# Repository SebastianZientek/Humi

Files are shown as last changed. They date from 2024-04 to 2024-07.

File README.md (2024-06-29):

# Klarta Humea WiFi Module Replacement

## Overview

This project offers a replacement WiFi module for the Klarta Humea humidifier, enabling users to control the device via a web interface. The project is written in C++ and utilizes the ESP8266 platform.

## Features
- Web-based control interface for managing the humidifier remotely.
- Custom PCB.
- Update firmware by OTA (On The Air)
- Control device over MQTT (allows integration with Home Assistant).

## PCB
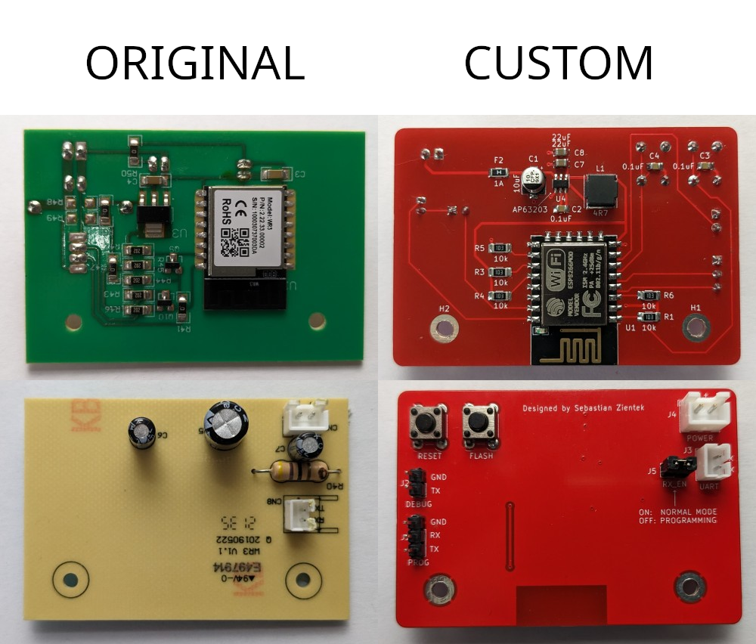
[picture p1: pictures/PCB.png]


## Web configuration portal
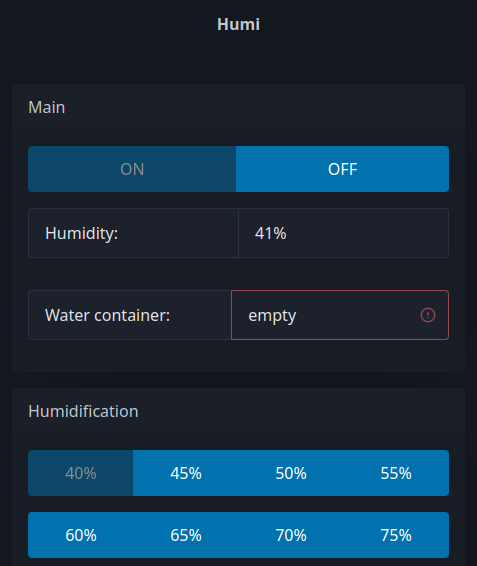
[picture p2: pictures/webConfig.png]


## Disclaimer

**Use at Your Own Risk**: This project is created for fun. While it works for me, I'm not an electronic engineer so keep in mind that PCB design can have mistakes.

## Getting Started

### Prerequisites

- [PlatformIO](https://platformio.org/) installed on your development environment (platformio-core or as plugin to your IDE).
- USB to TTL adapter for flashing the firmware.
- Prepared PCB (gerber files under pcb directory, values of components included on silkscreen)

### Firmware preparation
1. Clone this repository to your local machine:

   ```bash
   git clone https://github.com/SebastianZientek/Humi.git
   ```

2. Navigate to the project directory:

   ```bash
   cd Humi
   ```

### Flashing firmware

1. Connect the USB to TTL adapter to the `PROG` header on the custom PCB.

2. Connect the USB to TTL adapter to your computer.

3. Power on the Klarta Humea humidifier with the replacement WiFi module installed.

4. Disconnect jumper RX_EN.

5. Build and upload firmware to the board:

   ```bash
   pio run -t upload
   ```
6. Connect jumper back.

### First setup

1. Power on the Klarta Humea humidifier with the replacement WiFi module installed.
2. Connect to network hosted by humidifier (ssid: HumiConnectToWiFi).
3. Open a web browser and navigate to the `http://192.168.4.1`.
4. Set up wifi network that humidifier should use.

## Custom PCB

Custom PCB designs are provided under `PCB` directory. These files can be used to manufacture the replacement WiFi module PCB.

## License

This project is licensed under the [MIT License](LICENSE).

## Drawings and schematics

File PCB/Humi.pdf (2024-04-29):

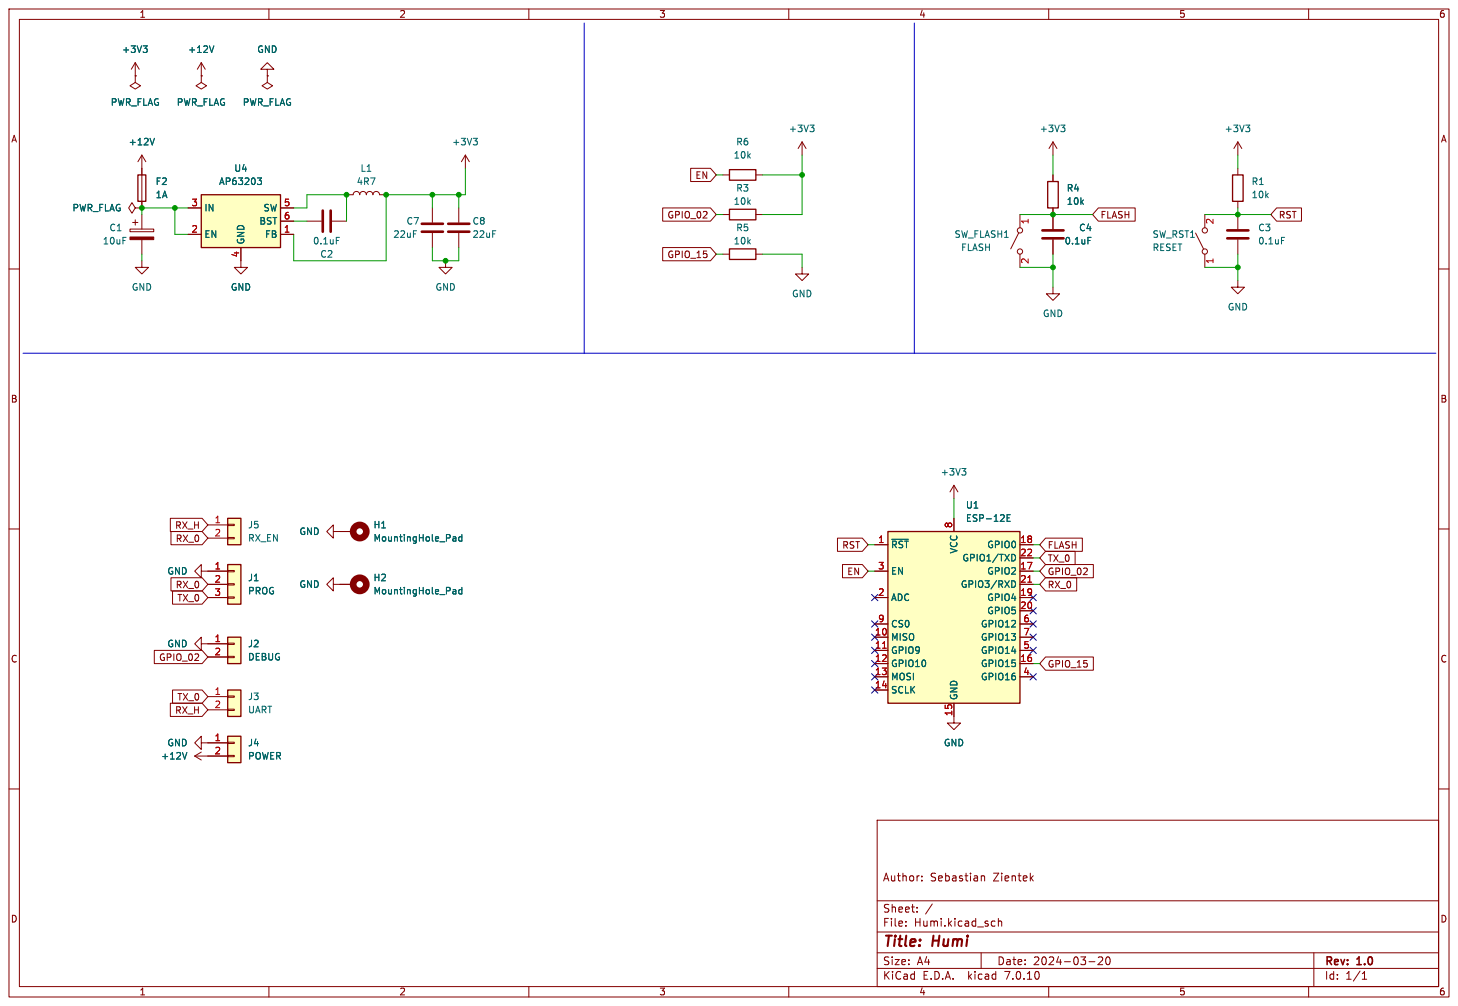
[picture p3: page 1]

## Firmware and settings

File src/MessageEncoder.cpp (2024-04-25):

#include "MessageEncoder.hpp"

#include <algorithm>
#include <iterator>
#include <map>
#include <numeric>
#include <optional>

namespace
{
constexpr auto preambleSize = 2;
constexpr auto headerSize = 6;
constexpr auto valueSize = 1;
constexpr auto checkSumSize = 1;
constexpr auto payloadSizeByteIndex = 5;

const std::map<std::string, std::vector<uint8_t>> encodingMap{
    {"power", {0, 6, 0, 5, 10, 1, 0, 1}},
    {"humidification_power", {0, 6, 0, 5, 106, 4, 0, 1}},
    {"humidification_level", {0, 6, 0, 5, 105, 4, 0, 1}},
    {"night_mode", {0, 6, 0, 5, 103, 1, 0, 1}},
    {"auto_mode", {0, 6, 0, 5, 104, 1, 0, 1}},
    {"light", {0, 6, 0, 5, 102, 4, 0, 1}},
    {"timer", {0, 6, 0, 5, 108, 4, 0, 1}},
    {"wifi_indicator", {0, 3, 0, 1}}};

const std::map<std::vector<uint8_t>, std::string> decodingMap{
    {{0, 0, 0}, "i_am_alive"},
    {{3, 4, 0}, "wifi_pair"},
    {{3, 7, 0, 5, 10, 1, 0, 1}, "power"},
    {{3, 7, 0, 5, 106, 4, 0, 1}, "humidification_power"},
    {{3, 7, 0, 5, 105, 4, 0, 1}, "humidification_level"},
    {{3, 7, 0, 5, 103, 1, 0, 1}, "night_mode"},
    {{3, 7, 0, 5, 104, 1, 0, 1}, "auto_mode"},
    {{3, 7, 0, 5, 102, 4, 0, 1}, "light"},
    {{3, 7, 0, 5, 108, 4, 0, 1}, "timer"},
    {{3, 7, 0, 5, 101, 4, 0, 1}, "water_lvl"},
    {{3, 7, 0, 8, 109, 2, 0, 4, 0, 0, 0}, "humidity_lvl"}};

auto findPreamble(std::span<uint8_t> dataRange)
{
    auto preamble = std::array<uint8_t, 2>{85, 170};  // NOLINT
    return std::search(dataRange.begin(), dataRange.end(), preamble.begin(), preamble.end());
}

template <typename It>
size_t getPayloadSize(It msgStartIt)
{
    auto playloadSizeIt = msgStartIt + payloadSizeByteIndex;
    return *playloadSizeIt;
}

template <typename It>
std::optional<It> getMessageEnd(It msgStartIt, It dataEnd)
{
    auto payloadSize = getPayloadSize(msgStartIt);

    size_t msgLength = headerSize + payloadSize + checkSumSize;
    size_t amountOfDataInBuffer = std::distance(msgStartIt, dataEnd);

    if (msgLength > amountOfDataInBuffer)
    {
        return std::nullopt;
    }

    return msgStartIt + msgLength;
}

std::span<uint8_t> getMessageRange(const std::span<uint8_t> &dataRange)
{
    std::pair<MessageEncoder::Msg, size_t> noMessageDecoded = {{}, 0};
    auto msgStartIt = findPreamble(dataRange);
    if (msgStartIt == dataRange.end())
    {
        // If there are no messages within the specified range, the function should return the end
        // of the range to skip the contents of the buffer.
        return {dataRange.end(), dataRange.end()};
    }

    auto msgEnd = getMessageEnd(msgStartIt, dataRange.end());
    if (!msgEnd.has_value())
    {
        // If there is no end of the message, the function should return the position where the
        // message preamble starts. This allows skipping the data in the buffer that precedes the
        // message.
        return {msgStartIt, msgStartIt};
    }

    auto msgEndIt = msgEnd.value();
    return std::span<uint8_t>{msgStartIt, msgEndIt};
}

std::string getMsgType(const std::span<uint8_t> &msg)
{
    // auto startMsgTypeIt = msg.begin() + headerSize;
    auto startMsgTypeIt = msg.begin() + preambleSize;
    auto endMsgTypeIt = msg.end() - valueSize - checkSumSize;

    if (startMsgTypeIt > endMsgTypeIt)
    {
        startMsgTypeIt = endMsgTypeIt;
    }

    std::vector<uint8_t> msgTypeData(startMsgTypeIt, endMsgTypeIt);
    if (decodingMap.find(msgTypeData) == decodingMap.end())
    {
        return "";
    }

    return decodingMap.at(msgTypeData);
}

uint8_t getValue(const std::span<uint8_t> &msg)
{
    return *(msg.end() - valueSize - checkSumSize);
}

bool isChecksumOk(const std::span<uint8_t> &msg)
{
    auto checkSumValue = *(msg.end() - valueSize);
    auto computedCheckSum = std::accumulate(msg.begin(), msg.end() - 1, 0) % 256;  // NOLINT

    return checkSumValue == computedCheckSum;
}
}  // namespace

std::pair<MessageEncoder::Msg, size_t> MessageEncoder::decodeFirsMsgInRange(
    std::span<uint8_t> buffer)
{
    auto msg = getMessageRange(buffer);
    size_t readedBytes = std::distance(buffer.begin(), msg.end());

    if (msg.empty())
    {
        return {{}, readedBytes};
    }

    if (!isChecksumOk(msg))
    {
        return {{}, readedBytes};
    }

    const auto msgType = getMsgType(msg);
    if (msgType.empty())
    {
        return {{}, readedBytes};
    }

    return {{msgType, getValue(msg)}, readedBytes};
}

std::vector<uint8_t> MessageEncoder::encode(const std::string &type, uint8_t value)
{
    std::vector<uint8_t> data;
    if (encodingMap.find(type) != encodingMap.end())
    {
        // Preamble
        data.insert(data.end(), {85, 170});  // NOLINT

        // Content
        const auto &content = encodingMap.at(type);
        data.insert(data.end(), content.begin(), content.end());

        // Value
        data.push_back(value);

        // Control sum
        uint8_t controlSum = std::accumulate(data.begin(), data.end(), 0) % 256;  // NOLINT
        data.push_back(controlSum);
    }
    return data;
}

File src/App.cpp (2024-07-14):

#include "App.hpp"

#include <Arduino.h>
#include <ArduinoOTA.h>
#include <fmt/format.h>

#include "Logger.hpp"
#include "WifiConfigurator.hpp"

void App::init()
{
    if (isEmergencyFlashingModeAfterCrash())
    {
        setupEmergencyFlashingOverOTA();
        return;
    }

    setupPeripherals();

    m_config.load();
    setupWifi();
    setupWebPage();
    setupDefaultState();
    setupHumidifierUart();
    setupMqtt();

    if (m_config.isOtaEnabled())
    {
        ArduinoOTA.begin();
    }

    setupTimers();
}

void App::update()
{
    if (isEmergencyFlashingModeAfterCrash())
    {
        ArduinoOTA.handle();
        delay(1000);
        return;
    }

    m_humidifierUartTimer.update();
    m_otaTimer.update();
    m_stateUpdateTimer.update();
    m_mqttHumidifier->update();

    if (m_shouldRestart)
    {
        Logger::info("Reboot");
        delay(1000);
        ESP.restart();
    }
}

void App::setupPeripherals()
{
    Serial.begin(m_serialSpeed);
    Serial1.begin(m_serialSpeed);

    Logger::init([](const std::string &txt) { Serial1.println(txt.c_str()); });
    if (!LittleFS.begin())
    {
        Logger::error("Can't initialize LittleFS");
    }

#ifdef LOGGER_ERR
    constexpr auto logLevel = Logger::LogLevel::ERROR;
#elif LOGGER_WRN
    constexpr auto logLevel = Logger::LogLevel::WARNING;
#elif LOGGER_INF
    constexpr auto logLevel = Logger::LogLevel::INFO;
#elif LOGGER_DBG
    constexpr auto logLevel = Logger::LogLevel::DEBUG;
#else
    constexpr auto logLevel = Logger::LogLevel::INFO;
#endif

    Logger::setLogLevel(logLevel);
}

void App::setupWifi()
{
    Logger::debug("Setup WiFi");
    m_humidifierUart.sendMessage("wifi_indicator", 2);
    WifiConfigurator::connectToWifi();
    m_humidifierUart.sendMessage("wifi_indicator", 4);
    Logger::info("Local IP {}", WiFi.localIP().toString().c_str());
}

void App::setupWebPage()
{
    Logger::debug("Setup WebPage");
    auto onWebMsgClbk = [this](const std::string &msgType, uint8_t value)
    { return m_humidifierUart.sendMessage(msgType, value); };
    auto onWebEventClbk = [this]()
    {
        m_webPage.sendEvent("humidifierState", m_humidifierState.dump().c_str());
        m_webPage.sendEvent("config", m_config.dumpWithoutPasswd().c_str());
    };
    auto onMqttConfigClbk = [this](bool enabled, const std::string &name, const std::string &user,
                                   const std::string &passwd, const std::string &ip, int port)
    {
        m_config.setMqttEnabled(enabled);
        m_config.setMqttName(name);
        m_config.setMqttUser(user);
        m_config.setMqttPasswd(passwd);
        m_config.setMqttIP(ip);
        m_config.setMqttPort(port);
        m_config.save();

        m_shouldRestart = true;
    };
    auto onOtaConfigClbk = [this](bool enabled)
    {
        m_config.setOtaEnabled(enabled);
        m_config.save();

        m_shouldRestart = true;
    };

    m_webPage.start(onWebMsgClbk, onWebEventClbk, onMqttConfigClbk, onOtaConfigClbk);
}

void App::setupDefaultState()
{
    m_humidifierState["humidification_level"] = 1;
    m_humidifierState["water_lvl"] = 1;
    m_humidifierState["power"] = 1;
    m_humidifierState["auto_mode"] = 0;
    m_humidifierState["night_mode"] = 0;
    m_humidifierState["light"] = 0;
}

void App::setupHumidifierUart()
{
    Logger::debug("Setup HumidifierUart");
    m_humidifierUart.setReceiveCallback(
        [this](const std::string &type, uint8_t value)
        {
            if (!type.empty())
            {
                if (m_humidifierState[type] != value)
                {
                    m_humidifierState[type] = value;
                    m_webPage.sendEvent("humidifierState",
                                        fmt::format(R"({{"{}": {}}})", type, value).c_str());
                    m_mqttHumidifier->publish(type, value);
                    Logger::debug("Read message: {}, value {}", type, value);
                }
            }
            if (type == "wifi_pair")
            {
                m_humidifierUart.sendMessage("wifi_indicator", 0);
                m_webPage.stop();
                WifiConfigurator::startConfigPortal();
                m_humidifierUart.sendMessage("wifi_indicator", 3);
                ESP.restart();
            }
        });
}

void App::setupMqtt()
{
    Logger::debug("Setup Mqtt");

    auto mqttDeviceId = std::to_string(ESP.getChipId());
    auto mqttDeviceName = m_config.getMqttName();
    auto mqttServer = m_config.getMqttIP();
    auto mqttPort = m_config.getMqttPort();
    auto mqttUsername = m_config.getMqttUser();
    auto mqttPassword = m_config.getMqttPasswd();

    m_mqttHumidifier = std::make_shared<MqttHumidifier<MqttAdp>>(
        m_mqttAdp, mqttDeviceName, mqttDeviceId, mqttServer, mqttPort, mqttUsername, mqttPassword);

    if (m_config.isMqttEnabled())
    {
        m_mqttHumidifier->start();
    }
    else
    {
        Logger::info("Mqtt disabled");
    }

    m_mqttHumidifier->setRecvCallback(
        [this](const std::string &msgType, uint8_t value)
        {
            Logger::debug("MQTT READ VALUES: {}, value {}", msgType, value);
            m_humidifierUart.sendMessage(msgType, value);
        });

    // send initial data
    for (auto it = m_humidifierState.begin(); it != m_humidifierState.end(); ++it)
    {
        std::string key = it.key();
        uint8_t value = it.value();
        Logger::debug("MQTT Initial send: {} = {}", key, value);
        m_mqttHumidifier->publish(key, value);
    }
}

void App::setupTimers()
{
    Logger::debug("Setup Timers");
    m_humidifierUartTimer.setCallback([this] { m_humidifierUart.update(); });
    m_humidifierUartTimer.start(250, true);

    m_otaTimer.setCallback(
        [this]
        {
            if (m_config.isOtaEnabled())
            {
                ArduinoOTA.handle();
            }
        });
    m_otaTimer.start(5000, true);

    m_humidifierUartTimer.setCallback([this] { m_humidifierUart.update(); });
    m_humidifierUartTimer.start(250, true);

    m_stateUpdateTimer.setCallback(
        [this]
        {
            auto mqttEnabled = m_config.isMqttEnabled();
            auto mqttState = mqttEnabled == false
                                 ? "disabled"
                                 : (m_mqttAdp->isConnected() ? "connected" : "disconnected");
            m_webPage.sendEvent("mqttState", mqttState);
            m_mqttHumidifier->publishWifi(WiFi.SSID().c_str(), WiFi.localIP().toString().c_str(),
                                          WiFi.RSSI());
        });

    m_stateUpdateTimer.start(10000, true);
}

void App::setupEmergencyFlashingOverOTA()
{
    auto resetReason = ESP.getResetInfoPtr()->reason;

    Serial1.begin(m_serialSpeed);
    Serial1.println("\nEMERGENCY FLASHING MODE");
    Serial1.print("Reset reason: ");
    Serial1.println(resetReason);

    WifiConfigurator::connectToWifi();
    ArduinoOTA.begin();
}
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

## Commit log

2024-03-12 Buttons handling on view and split js from html (#4)
2024-04-29 License, readme and gerbers (#16)
    [Humi-B_Cu.gbr, Humi-B_Mask.gbr, Humi-B_Paste.gbr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]
2024-06-30 Fix sended state (disapearing water tank state) (#25)
    [App.cpp]
2024-07-14 Improved switching between mode and target humidity (#27)
